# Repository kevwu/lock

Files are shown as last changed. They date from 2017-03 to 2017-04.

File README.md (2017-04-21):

# Lock

This repository contains the code + designs for a Raspberry Pi-controlled deadbolt.

## Required Hardware
- Raspberry Pi Zero W
- [Stepper motors](https://www.amazon.com/Industry-Park-28BYJ-48-Stepper-ULN2003/dp/B01J507JGS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)
  - These are everywhere, they're incredibly common. I found that the 5V version wasn't powerful enough to move my deadbolt and kept getting stuck, so I got the 12V ones linked here. If you do this, just get a 12V 1A power supply, cut off the end and solder the +/- wires to some female headers. Then hook the output up to the driver (they take 5-12V.)

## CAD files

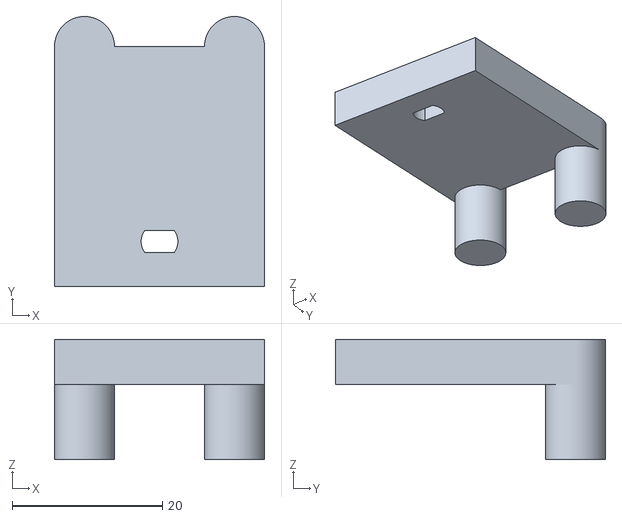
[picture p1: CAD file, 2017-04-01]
stl/grabber_long.stl
28.0 x 36.0 x 16.0

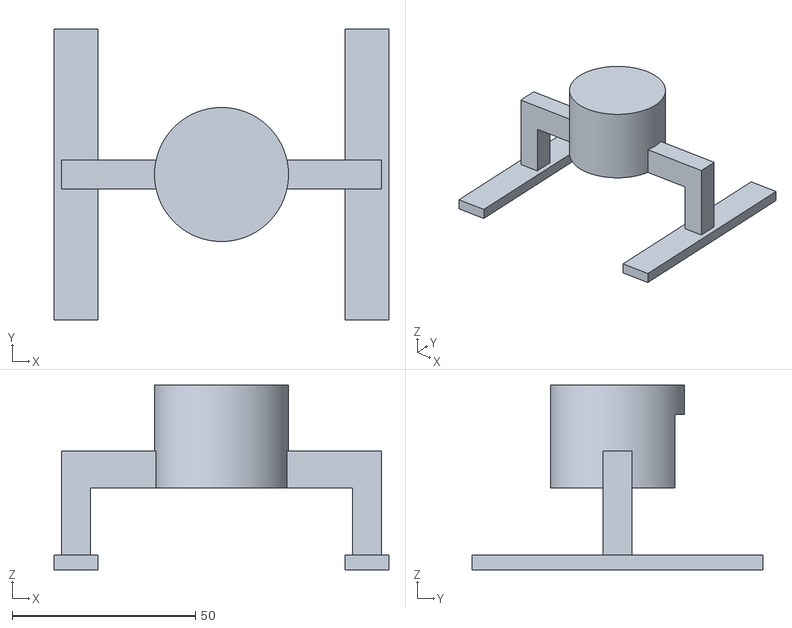
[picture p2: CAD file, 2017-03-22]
stl/motor_case.stl
91.5 x 79.5 x 50.4

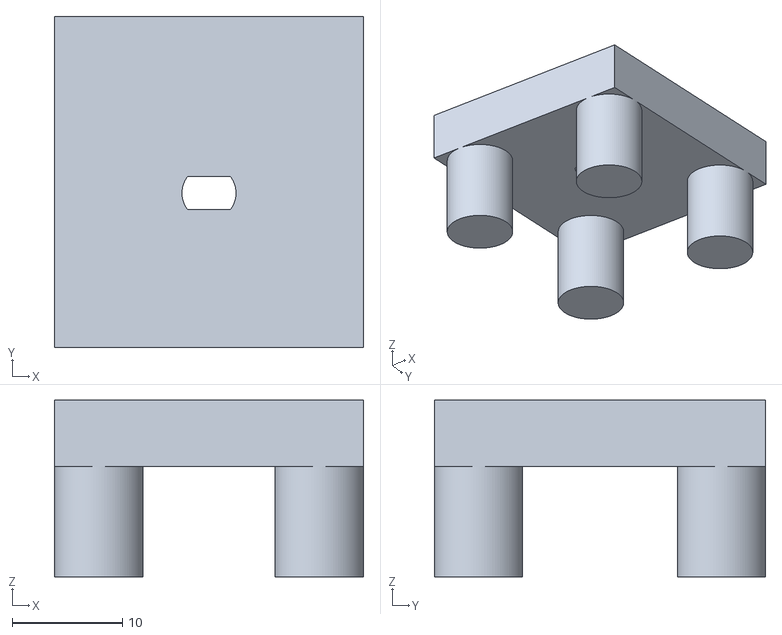
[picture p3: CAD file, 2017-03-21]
stl/handle_grabber.stl
28.0 x 30.0 x 16.0

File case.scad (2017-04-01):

// cylindrical base of deadbolt
base_dia = 63.5;
base_height = 4.8;

// handle
handle_height_max = 8;
handle_width_max = 14.3;
// handle width on long end
handle_width_min_long = 6.35;
// handle width on short end
handle_width_min_short = 7.9;

handle_length = base_dia;
// tiny cylindrical base on which handle sits and swivels
// (diameter is entirely below the handle, so it is irrelevant)
handle_base = 1.6;

stepper_shaft_dia = 4.9;
// width of notched part of shaft
stepper_shaft_notch = 3;
// length of notched part of shaft
stepper_shaft_length = 6;

base_wall_thickness = 10;
// additional space above/below the deadbolt to allow for positioning
base_vertical_leeway = 5;

module base() {
	// enclose deadbolt base
	difference() {
		cube([base_dia + 2*base_wall_thickness, base_dia + 2*base_wall_thickness + base_vertical_leeway, base_height]);

		translate([base_wall_thickness, base_wall_thickness, 0]) {
			cube([base_dia, base_dia + base_vertical_leeway, base_height]);
		}
	}

	// motor mount

	// supports over deadbolt handle
	translate([0, base_wall_thickness + base_vertical_leeway/2, base_height]) {
		cube([base_wall_thickness, base_dia, handle_base + handle_height_max]);
	}

	translate([base_wall_thickness + base_dia, base_wall_thickness + base_vertical_leeway/2, base_height]) {
		cube([base_wall_thickness, base_dia, handle_base + handle_height_max]);
	}
}

// deadbolt handle. Not used in product, but helps with dimensioning.
module handle(){
	linear_extrude(height=handle_height_max) {
		// long end
		polygon([
			[0,0],
			[(handle_width_max - handle_width_min_long)/2, (handle_length - 25)],
			[handle_width_max - (handle_width_max - handle_width_min_long)/2, (handle_length-25)],
			[handle_width_max,0],
		]);

		// short end
		polygon([
			[0,0],
			[(handle_width_max - handle_width_min_short)/2, -25],
			[handle_width_max - (handle_width_max - handle_width_min_short)/2, -25],
			[handle_width_max,0],
		]);
	}
}

// handle "grabber"
module grabber() {
	cyl_dia = 8;
	cyl_height = handle_height_max + stepper_shaft_length + 2;
	difference() {
		union() {
			translate([10, 12, 0])
				cylinder(h=cyl_height, d=cyl_dia, $fn = 100);
			translate([-10,12,0])
				cylinder(h=cyl_height, d=cyl_dia, $fn = 100);
			translate([10,-10,0])
				cylinder(h=cyl_height, d=cyl_dia, $fn = 100);
			translate([-10,-10,0])
				cylinder(h=cyl_height, d=cyl_dia, $fn = 100);
			translate([0, 1 ,cyl_height - stepper_shaft_length/2])
				cube([20 + cyl_dia, 22 + cyl_dia ,stepper_shaft_length], center=true);
		}

		intersection() {
			cylinder(h=50, d=stepper_shaft_dia, $fn = 50);
			cube([stepper_shaft_dia, stepper_shaft_notch, 50], center=true);
		}
	}
}

// longer version of grabber (for longer lever arm)
module grabber_long() {
	cyl_dia = 8;
	cyl_height = handle_height_max + stepper_shaft_length + 2;
	difference() {
		union() {
			translate([10, 26, 0])
				cylinder(h=cyl_height, d=cyl_dia, $fn = 100);
			translate([-10,26,0])
				cylinder(h=cyl_height, d=cyl_dia, $fn = 100);
			translate([0, 10 ,cyl_height - stepper_shaft_length/2])
				cube([20 + cyl_dia, 24 + cyl_dia ,stepper_shaft_length], center=true);
		}

		intersection() {
			cylinder(h=50, d=stepper_shaft_dia, $fn = 50);
			cube([stepper_shaft_dia, stepper_shaft_notch, 50], center=true);
		}
	}
}

stepper_motor_dia = 28.6;
stepper_motor_height = 20;
stepper_motor_flange_length = 8;
stepper_motor_hole_dia = 3.17;
stepper_wire_breakout = 19;

// case for motor
module motor_case() {
	difference() {
		case_thickness = 8;
		// outer casing
		union() {
			cylinder(h=stepper_motor_height + case_thickness, d=stepper_motor_dia + case_thickness, $fn=300);

			// cross-beam (for mounting and flanges)
			translate([0,0,5]) {
				cube([base_dia + 3*case_thickness, stepper_motor_flange_length, 10], center=true);
			}

			column_height = base_height + handle_base + handle_height_max + stepper_shaft_length;

			// base (for mounting onto door)
			translate([base_dia/2 + case_thickness, 0, 0]) {
				// column
				translate([0,0,-10]) {
					cube([case_thickness, stepper_motor_flange_length, column_height], center=true);
				}
				// skid
				translate([0,0,-column_height]) {
					cube([1.5*case_thickness, base_dia + 2*case_thickness, case_thickness/2], center=true);
				}
			}

			translate([-(base_dia/2 + case_thickness),0,0]) {
				// column
				translate([0,0,-10]) {
					cube([case_thickness, stepper_motor_flange_length, column_height], center=true);
				}
				// skid
				translate([0,0,-column_height]) {
					cube([1.5*case_thickness, base_dia + 2*case_thickness, case_thickness/2], center=true);
				}
			}
		}

		union() {
			// motor hole
			cylinder(h=stepper_motor_height, d=stepper_motor_dia, $fn = 300);

			// wire breakout hole
			translate([0, stepper_motor_dia/2, stepper_motor_height/2]) {
				cube([stepper_wire_breakout, 10, stepper_motor_height], center=true);
			}
		}
	}
}

translate([-(handle_width_max)/2,0,0]) {
	%handle();
}

// handle's axis of rotation is not centered on base. 5mm here is eyeballed
translate([0, 5, -base_height]) {
	%cylinder(h=base_height, d=base_dia, $fn = 100);
}

!grabber_long();
translate([0,0,handle_base + handle_height_max + stepper_shaft_length + 5]) {
	motor_case();
}

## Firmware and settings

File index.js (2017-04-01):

let express = require("express")
let app = express()
let http = require("http")

let rpio = require("rpio")

// snap-action switches
const LOCKED_SWITCH = 16
const UNLOCKED_SWITCH = 18

// physical button for manually opening/closing
const BUTTON = 15

rpio.open(LOCKED_SWITCH, rpio.INPUT, rpio.PULL_UP)
rpio.open(UNLOCKED_SWITCH, rpio.INPUT, rpio.PULL_UP)

// represents four-pin stepper motor
class Stepper {
	constructor(pins) {
		this.pins = pins

		// timeout for running motor
		this.runTimeout = null

		// open all, set to low
		for(let i = 0; i < 4; i += 1) {
			rpio.open(this.pins[i], rpio.OUTPUT, rpio.LOW)
		}
	}

	// run forward
	run(reverse = false) {
		// halt first
		this.halt()

		// pin counter
		let p = 0;
		// usual stepper motor business
		this.runTimeout = setInterval(() => {
			rpio.write(this.pins[wrapIndex(p-1, 4)], rpio.LOW)
			rpio.write(this.pins[p], rpio.HIGH)
			rpio.write(this.pins[wrapIndex(p+1, 4)], rpio.HIGH)

			if(!reverse) {
				p = wrapIndex(p + 1, 4)
			} else {
				p = wrapIndex(p - 1, 4)
			}

			// Switches are backwards - 1 is open, 0 is pressed

			if(!rpio.read(LOCKED_SWITCH) && !reverse) {
				this.halt()
			}

			if(!rpio.read(UNLOCKED_SWITCH) && reverse) {
				this.halt()
			}

		}, 5) 
	}

	// stops motor and removes resistance (so it can be turned by hand)
	halt() {
		console.log("Stopping.")
		clearInterval(this.runTimeout)

		for(let i = 0; i < 4; i += 1) {
			rpio.write(this.pins[i], rpio.LOW)
		}
	}
}

let server = http.createServer(app).listen(8080, function() {
	console.log("HTTP server listening.");
})

let motor = new Stepper([7,8,10,12])

app.get("/", (req, res) => {
	res.sendFile("index.html")
})

app.get("/open", (req,res) => {
	open()
	res.end()
})

app.get("/close", (req, res) => {
	close()
	res.end()
})

app.get("/forward", (req, res) => {
	motor.run(reverse=false)
	res.end()
})

app.get("/reverse", (req, res) => {
	motor.run(reverse=true)
	res.end()
})

app.get("/halt", (req, res) => {
	motor.halt()
	res.end()
})

// watch for switches
rpio.poll(LOCKED_SWITCH, (pin) => {
	// if door is currently unlocked, pressing the locked trigger manually locks the door
	if(!rpio.read(UNLOCKED_SWITCH)) {
		console.log("Manually locking.")
		close()
	}
})

rpio.poll(UNLOCKED_SWITCH, (pin) => {
	if(!rpio.read(LOCKED_SWITCH)) {
		console.log("Manual unlocking.")
		open()
	}
})

// manual button
rpio.poll(BUTTON, () => {

})

function open() {
	// switch states are reversed - 0 is depressed, 1 is released
	if(rpio.read(UNLOCKED_SWITCH)) {
		console.log("Unlocking...")
		motor.run(reverse=true)
	} else {
		console.log("Already unlocked.")
	}
}

function close() {
	if(rpio.read(LOCKED_SWITCH)) {
		console.log("Locking...")
		motor.run()
	} else {
		console.log("Already locked.")
	}
}

// because JS modulo isn't actually modulo (via Stack Overflow)
function wrapIndex(i, i_max) {
	return ((i % i_max) + i_max) % i_max;
}

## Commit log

2017-03-20 Initial commit, designed base
    [case.scad]
2017-03-20 Model handle
    [case.scad]
2017-03-21 Add grabber
    [case.scad, handle_grabber.stl]
2017-03-22 Added motor case
    [case.scad]
2017-03-22 Expand motor case
    [case.scad]
2017-03-22 Add motor case
    [case.scad, motor_case.stl]
2017-03-23 Motor control, basic HTTP endpoints
    [handle_grabber.stl, motor_case.stl]
2017-03-23 Use real GPIO pin values, fix stepper instructions, add additional commands
    [index.js]
2017-03-24 Mess with switch GPIO, trying to figure out weird behavior
2017-03-30 Remove unreliable polling, fix directions
    [index.js]
2017-04-01 Add longer grabber for more torque
    [case.scad, grabber_long.stl]
